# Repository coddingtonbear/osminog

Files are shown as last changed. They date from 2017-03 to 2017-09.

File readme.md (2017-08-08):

# Octoprint-3D Printer Extras (Osminog)



I have a 3D printer managed by Octoprint in my basement and would rather
that I be able to turn on/off the fan and LED lighting supporting
that printer programmatically via Octoprint's events API.

What this provides is a USB device allowing me to:

* Turn the power outlet supporting the LED lighting and 3D printer
  off or on.
* Switch DC power to a LED lighting strip.
* Gather temperature and humidity measurements.
* Watch whether I'm nearly out of filament using a [cheap filament sensor off of Ebay](https://www.ebay.com/i/371913487805?chn=ps&dispItem=1).
* Beep when paused or when a print has completed.  This is useful for knowing when to change filament or when I need to insert a captive bolt or magnet.

## Commands

* ``POWERON``: Turn on the RF-controlled outlet
* ``POWEROFF``: Turn off the RF-controlled outlet
* ``GETTEMPERATURE``: Return the current temperature (Celsius)
* ``GETHUMIDITY``: Return the current humidity level
* ``BUZZER``: Buzz the buzzer for half a second
* ``FILAMENT``: Return a "1" or "0" depending upon whether filament is detected in the filament sensor.

## Schematic



## Errata

* In the photo above of the final board, you'll see two bodges; those are there
  to support programming the device via the USB port.  In the uploaded
  schematics, the board has been corrected to include that resistor and
  capacitor.

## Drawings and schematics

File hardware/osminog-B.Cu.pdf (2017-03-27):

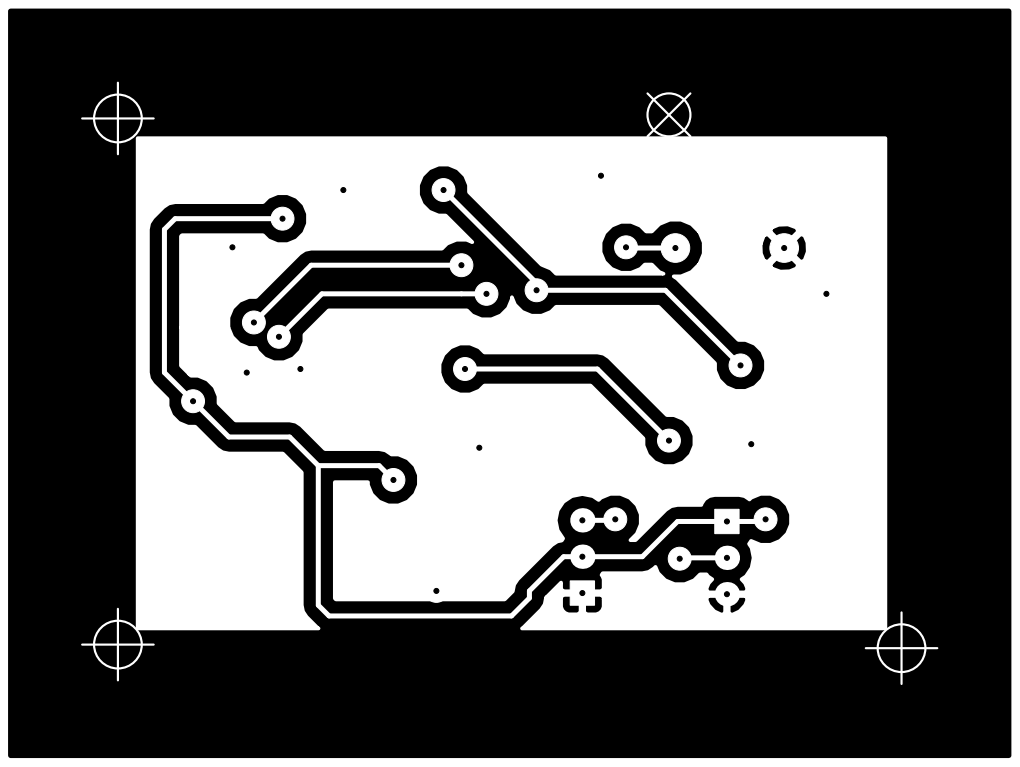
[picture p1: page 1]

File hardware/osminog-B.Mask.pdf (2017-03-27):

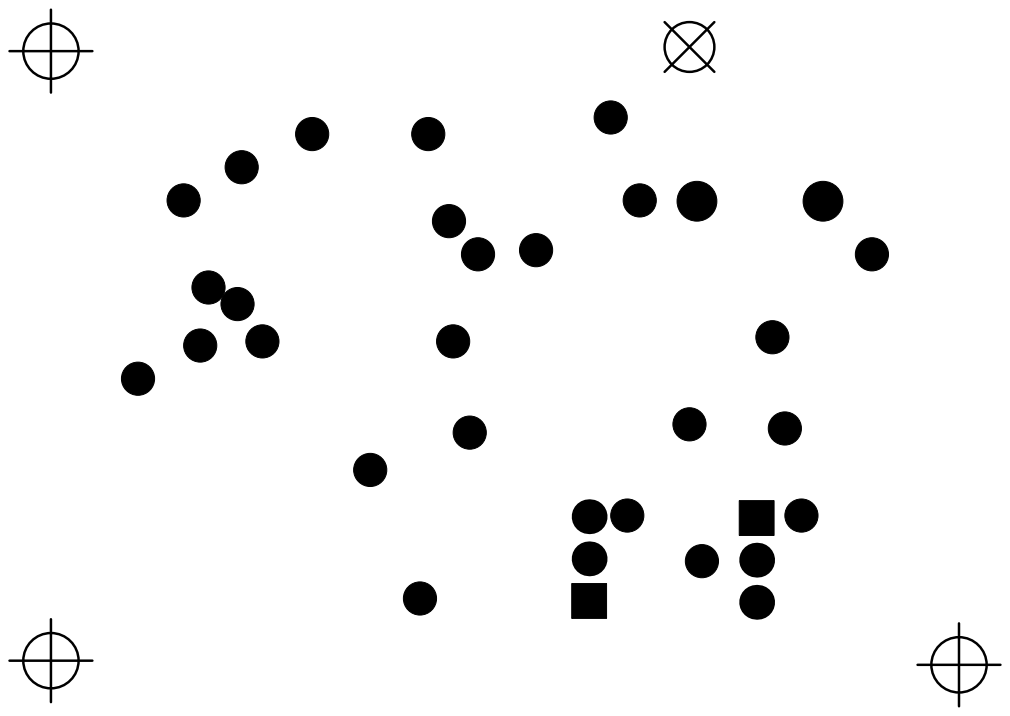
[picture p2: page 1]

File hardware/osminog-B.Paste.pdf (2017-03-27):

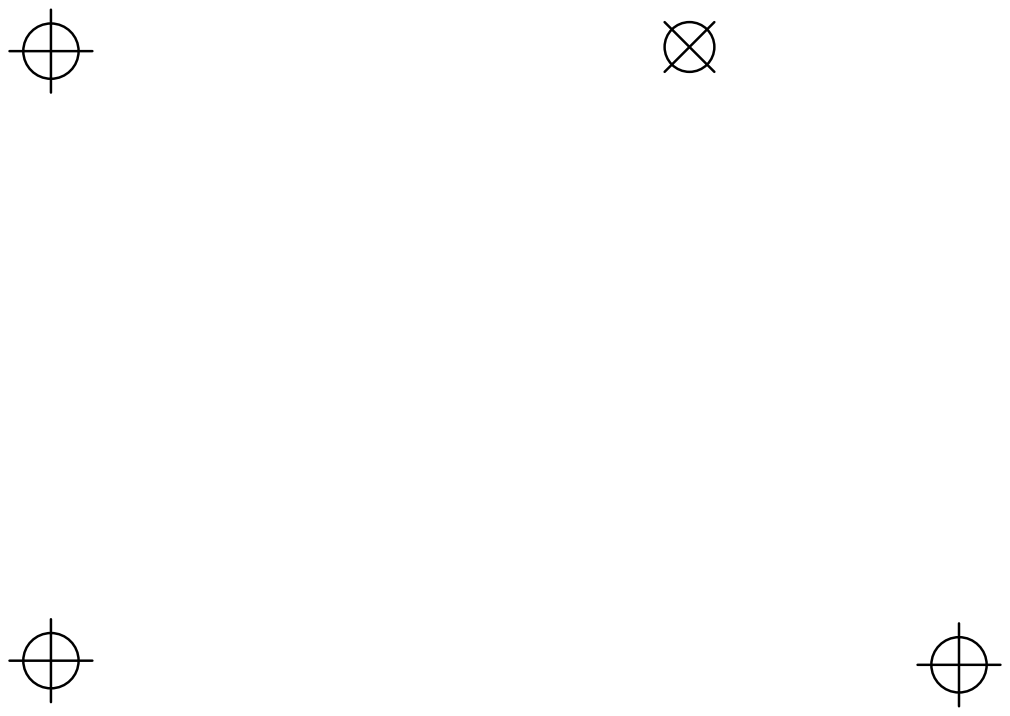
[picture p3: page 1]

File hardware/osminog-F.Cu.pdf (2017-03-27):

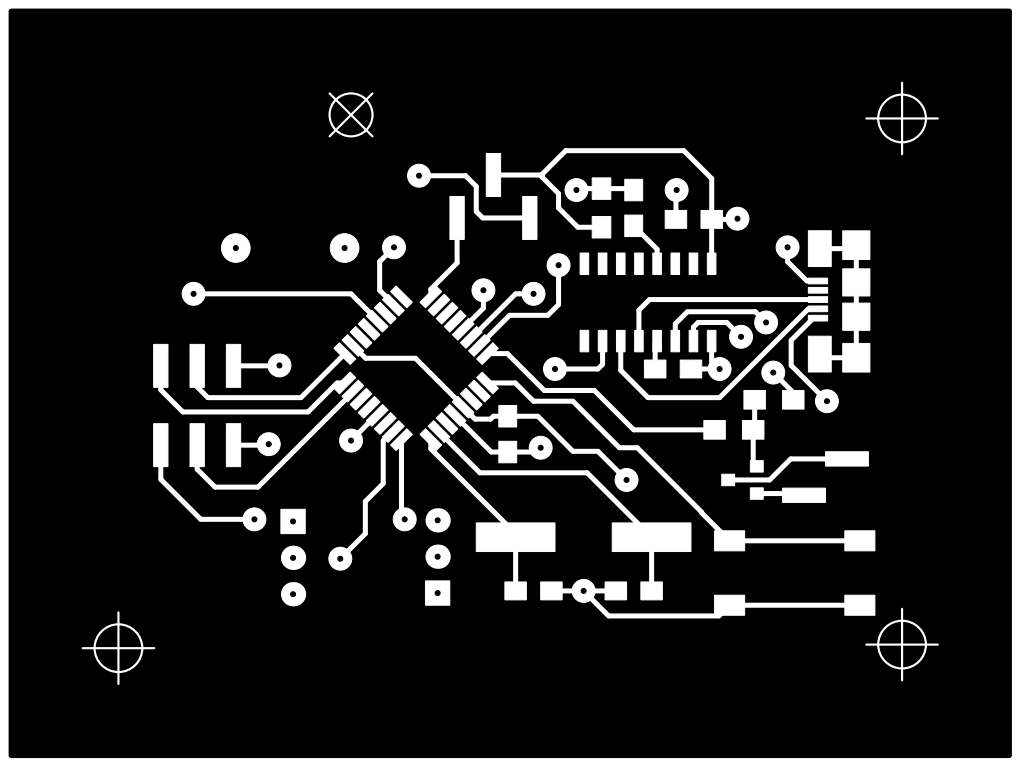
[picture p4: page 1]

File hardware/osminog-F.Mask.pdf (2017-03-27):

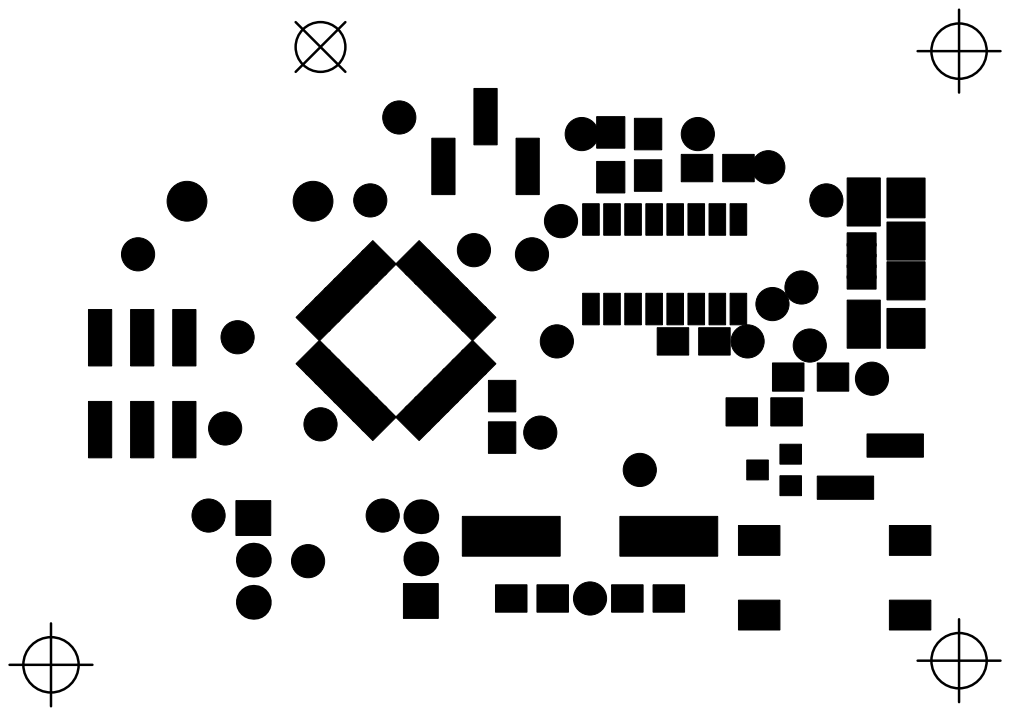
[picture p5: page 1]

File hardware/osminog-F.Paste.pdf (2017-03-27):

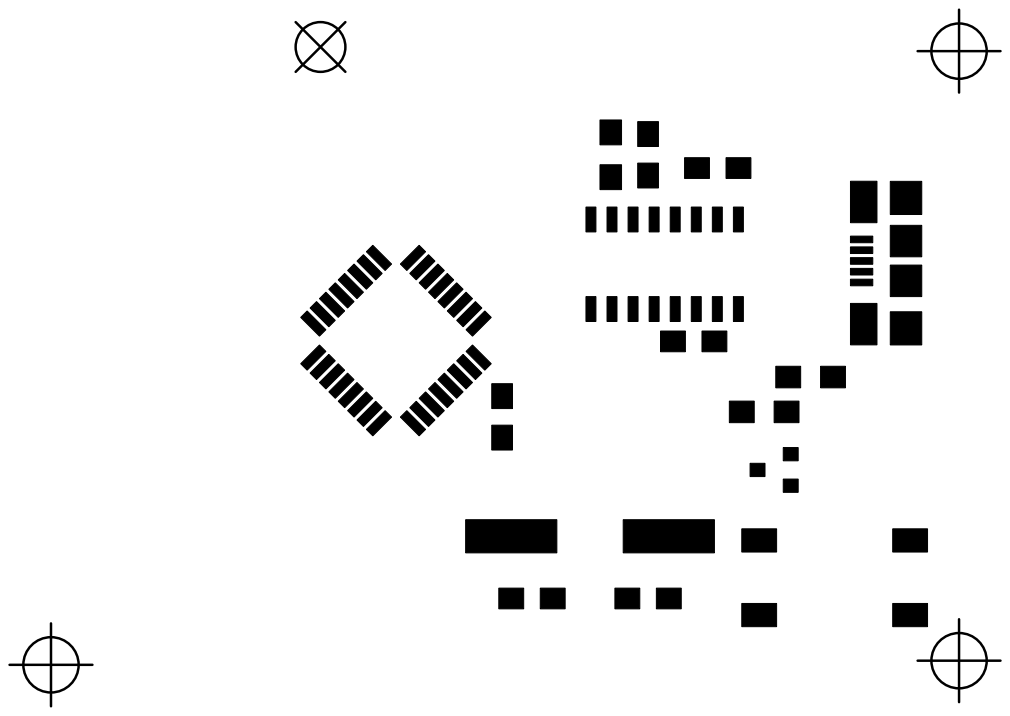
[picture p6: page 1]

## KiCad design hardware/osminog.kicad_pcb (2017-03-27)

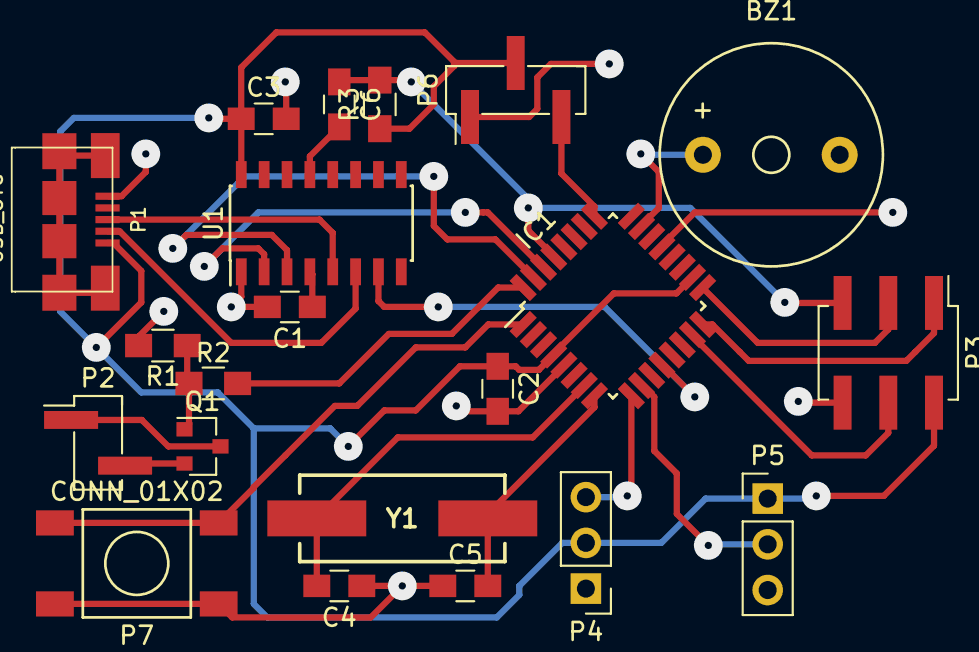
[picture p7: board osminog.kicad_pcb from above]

Board: 2 copper layers, 21 parts (0 on the bottom side), 24 nets.

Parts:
BZ1: Buzzer; Buzzer_12x9.5RM7.6
C1, C2, C3, C6: 0.1u; C_0805_HandSoldering
C4, C5: 22p; C_0805_HandSoldering
IC1: ATMEGA328PB-A; TQFP-32_7x7mm_Pitch0.8mm
P1: USB_OTG; MICRO-B_USB-INVERTED
P2: CONN_01X02; Pin_Header_Straight_1x02_Pitch2.54mm_SMD_Pin1Left
P3: CONN_02X03; Pin_Header_Straight_2x03_Pitch2.54mm_SMD
P4, P5: CONN_01X03; Pin_Header_Straight_1x03_Pitch2.54mm
P6: CONN_01X03; Pin_Header_Straight_1x03_Pitch2.54mm_SMD_Pin1Left
P7: CONN_01X02; SWITCH_FSM_JSM_off-mom
Q1: BSS138; SOT-23
R1, R3: 10k; R_0805_HandSoldering
R2: 470; R_0805_HandSoldering
U1: CH340G; SOIC-16_3.9x9.9mm_Pitch1.27mm
Y1: 12; HC-49S

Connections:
+5V: C2.1, C3.1, IC1.4, IC1.18, P1.1, P3.2, P4.2, P5.1, P6.2, R3.1, U1.16
BUZZER: BZ1.1, IC1.23
CLKOUT: IC1.12, U1.7
ENABLE_RELAY: IC1.32, R2.2
GND: BZ1.2, C1.2, C2.2, C3.2, C4.1, C5.1, IC1.5, IC1.21, P1.5, P3.6, P4.1, P5.3, P6.1, P7.2, R1.2, U1.1
LED: IC1.25, P6.3
MISO: IC1.16, P3.1
MOSI: IC1.15, P3.4
unnamed: C1.1, U1.4
unnamed: C4.2, IC1.7, Y1.1
unnamed: C5.2, IC1.8, Y1.2
unnamed: C6.2, U1.13
unnamed: IC1.30, U1.2
unnamed: IC1.31, U1.3
unnamed: P1.2, U1.6
unnamed: P1.3, U1.5
unnamed: P2.1, Q1.3
unnamed: P2.2, Q1.2
unnamed: Q1.1, R1.1, R2.1
RESET: C6.1, IC1.29, P3.5, R3.2
SCK: IC1.17, P3.3
SWITCH: IC1.1, P7.1
TEMP: IC1.10, P5.2
XMIT: IC1.9, P4.3

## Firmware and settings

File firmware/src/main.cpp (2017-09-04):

#include "main.h"

#define DHT_11_PIN 6

#define OUTLET_PIN 5
#define OUTLET_ON 5574000
#define OUTLET_OFF 5573952

#define BUTTON_PIN 3

#define RELAY_PIN 2

#define FILAMENT_PIN 16

#define BUZZER_PIN A0


DHT dht(DHT_11_PIN, DHT11);
RCSwitch outletSwitch = RCSwitch();
Bounce button = Bounce();
SerialCommand cmd;

bool poweredOn = false;


void setup() {
    Serial.begin(9600);
    outletSwitch.enableTransmit(OUTLET_PIN);

    dht.begin();

    pinMode(BUTTON_PIN, INPUT_PULLUP);
    button.attach(BUTTON_PIN);
    button.interval(50);

    pinMode(BUZZER_PIN, OUTPUT);
    soundBuzzer(100);

    pinMode(FILAMENT_PIN, INPUT);

    cmd.addCommand("POWEROFF", powerOff);
    cmd.addCommand("POWERON", powerOn);
    cmd.addCommand("GETTEMPERATURE", getTemperature);
    cmd.addCommand("GETHUMIDITY", getHumidity);
    cmd.addCommand("BUZZER", soundBuzzer);
    cmd.addCommand("FILAMENT", checkFilament);
    cmd.addDefaultHandler(unrecognized);
    Serial.println("Osminog 1.0 Ready");
}

void unrecognized() {
    Serial.println("Error");
}

void checkFilament() {
    Serial.println(digitalRead(FILAMENT_PIN));
}

void powerOn() {
    Serial.println("OK");
    outletSwitch.send(OUTLET_ON, 24);
    poweredOn = true;
}

void powerOff() {
    Serial.println("OK");
    outletSwitch.send(OUTLET_OFF, 24);
    poweredOn = false;
}

void getTemperature() {
    Serial.println(dht.readTemperature());
}

void getHumidity() {
    Serial.println(dht.readHumidity());
}


void soundBuzzer() {
    soundBuzzer(500);
}


void soundBuzzer(int milliseconds) {
    Serial.println("OK");
    digitalWrite(BUZZER_PIN, HIGH);
    delay(milliseconds);
    digitalWrite(BUZZER_PIN, LOW);
}


void loop() {
    cmd.readSerial();

    button.update();
    if(button.fell()) {
        if (poweredOn) {
            powerOff();
        } else {
            powerOn();
        }
    }
}

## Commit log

2017-03-16 And so it begins...
    [osminog.kicad_pcb, osminog.sch]
2017-03-19 Updating to use ATMEGA328pb...at less than 2USD, I might as well.
    [osminog.kicad_pcb, osminog.sch]
2017-03-27 Adding latest version of osminog.
    [osminog.kicad_pcb, osminog.sch]
2017-03-27 Updating readme to include photo and schematic.
2017-03-27 Updating schematic to include some missing values.
    [osminog.sch]
2017-08-07 Hook to poweroff/poweron instead of print stopped/started.
2017-08-08 Adding filament sensor commands.
2017-08-08 Better reconnect handling; require two sequential filament check failures.
2017-08-08 Also beep if the print completed normally.
2017-08-08 Relabeling 'LED' to 'FILAMENT' to describe that pins current function.
    [osminog.sch]
2017-08-30 Do not bother with gathering multiple filament check results.
2017-09-04 Slightly more robust handling of beeps and buzzes.
    [main.cpp]
